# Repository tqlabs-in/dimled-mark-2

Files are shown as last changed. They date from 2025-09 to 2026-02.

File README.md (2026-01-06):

# DimLED Mark II

A simple led dimmer based on ESP-01 Module powered by esphome firmware.

Checkout [iBOM](https://htmlpreview.github.io/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) for more details.

### Renders ( Mark II.b )

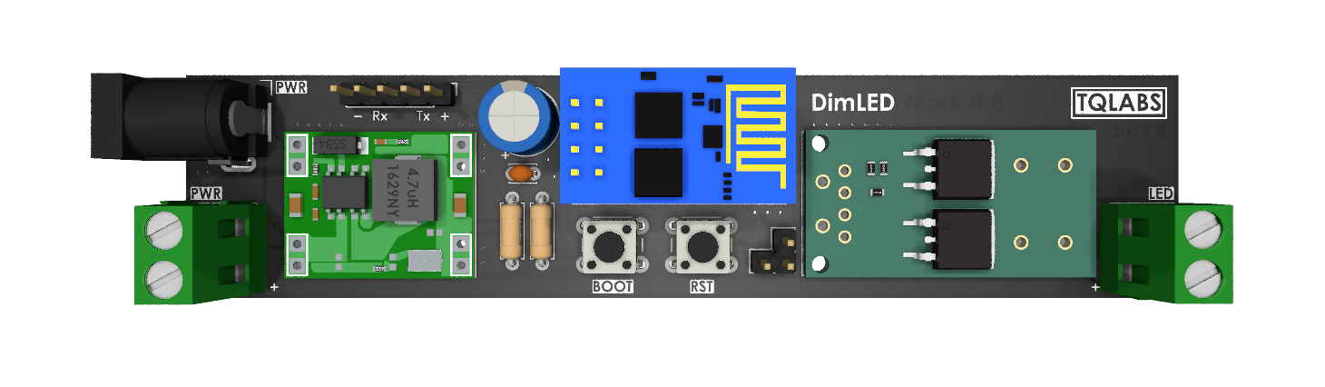
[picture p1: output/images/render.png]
DimLED Mark IIb

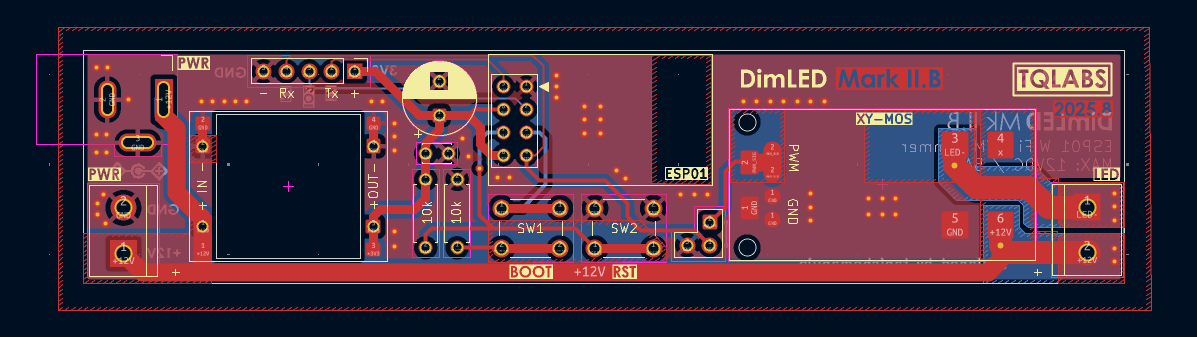
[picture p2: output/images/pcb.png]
PCB


### Operating Power

Max Values:

- Max Voltage: 36VDC
- Max Current: 15A
- Max Power: 400W

> Above specs are contstrained by XY-MOS PWM Trigger Module

Recommended Values:

- less than 10A at 12VDC
- less than 6A at 24VDC

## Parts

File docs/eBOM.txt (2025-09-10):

# Estimate BOM
Date: 13-8-2025

1.	ESP-01 ESP8266			Rs 86	https://robu.in/product/esp-01-esp8266-serial-wifi-wireless-transceiver-module/
2. 	XY-MOS Trigger Module		Rs 25	https://robu.in/product/switch-drive-high-power-mosfet-trigger-module/
3.	Mini MP1584 Buck Module		Rs 34	https://robu.in/product/mini-mp1584-dc-dc-3a-adjustable-buck-module-india/	
4.	2 Pin Screw Block		Rs 10	https://robu.in/product/2-pin-straight-pcb-screw-terminal-block-connector-3-5mm-pitch/
5.	DC-005A Connector		Rs 9	https://robu.in/product/dc-jack-005a/
6.	Tactile Push Button		Rs 2	https://robu.in/product/6x6x5-tactile-push-button-switch/
7.	1000uF THT Radial Capacitor	Rs 8	https://robu.in/product/ers1am102f16ot-aishi-1000uf-10v-%c2%b120-plugind8x16mm-aluminum-electrolytic-capacitors-leaded-rohs/
8.	100nF THT Disk Cap		Rs 1	https://robu.in/product/100nf-50v-through-hole-multilayer-ceramic-capacitor/

X. Component Total			Rs 187	[ 1 x 1,2,3,5,6,7,8 -- 2 x 4 ]
Y. Extras				Rs 9	[ Basic Resistors, ESP01 Headers ]
Z. PCB					Rs 144	[ Robu: 10 for Rs 1440 ]

T. Grand Total				Rs 340

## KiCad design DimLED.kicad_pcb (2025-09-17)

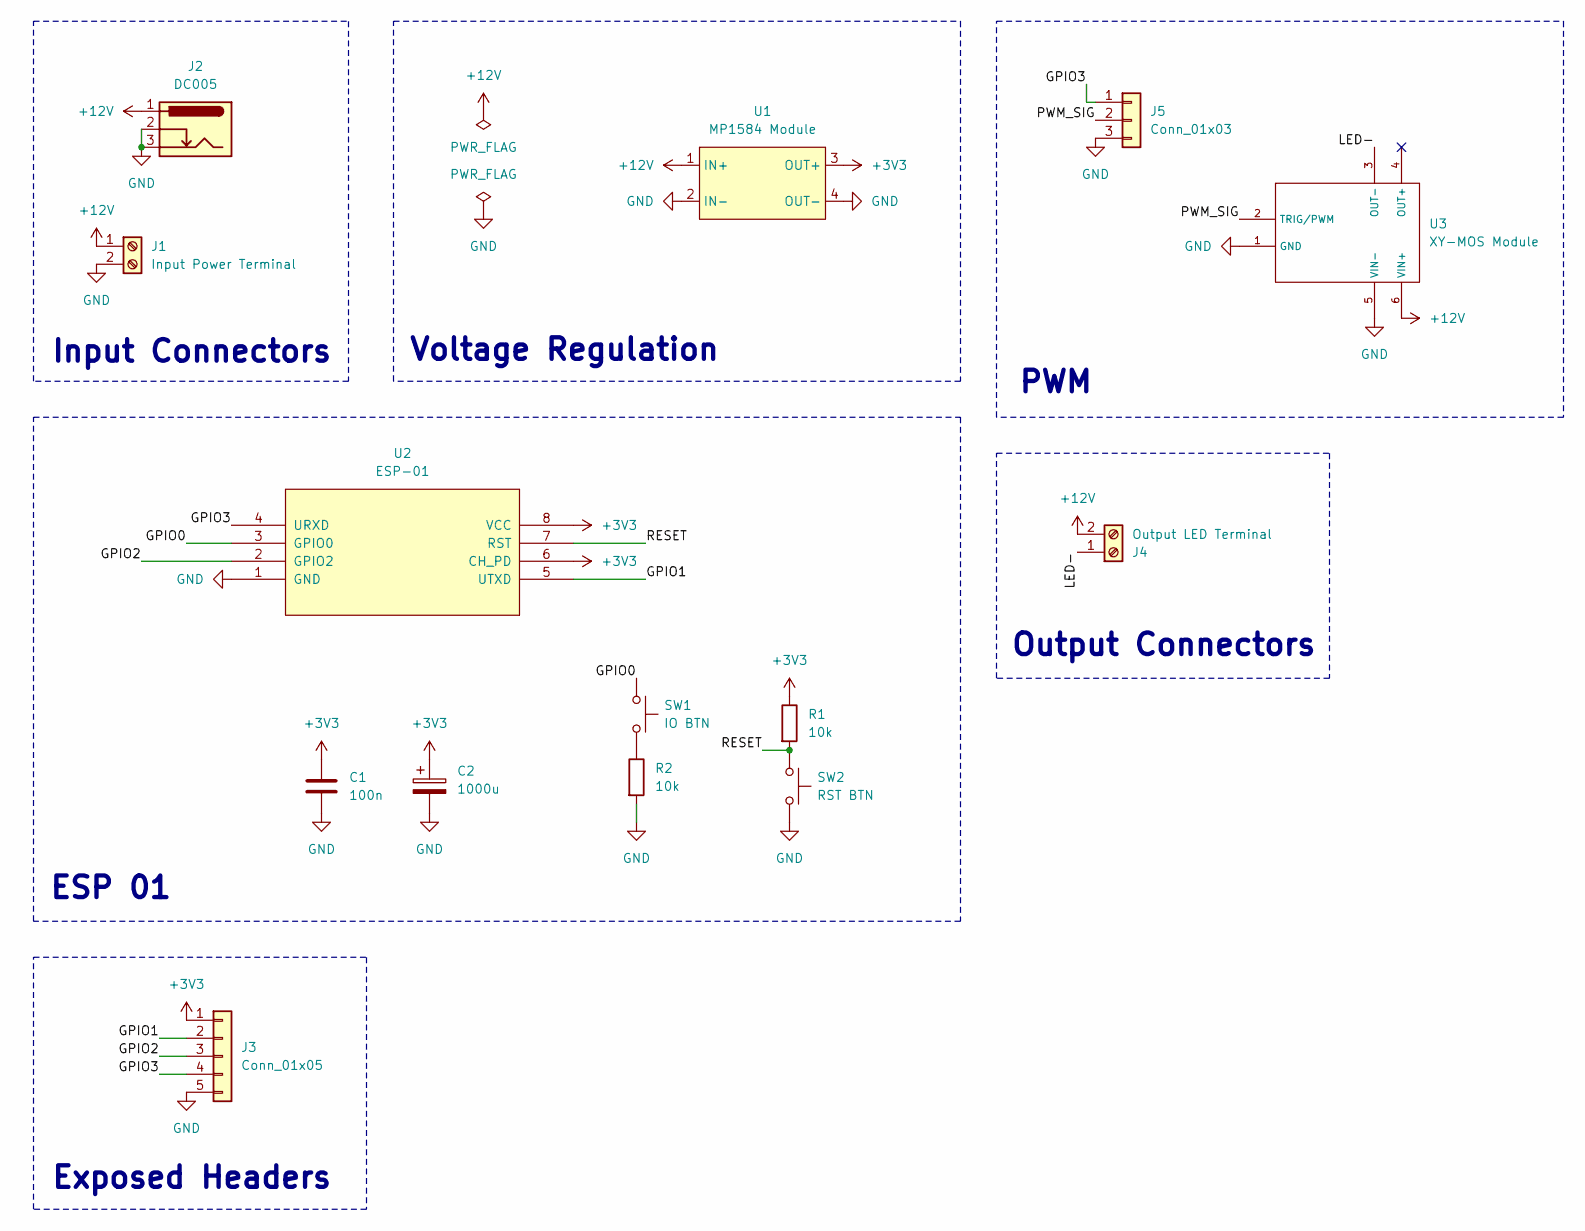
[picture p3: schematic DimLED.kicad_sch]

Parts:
C1: 100n; C_Disc_D3.0mm_W2.0mm_P2.50mm
C2: 1000u; CP_Radial_D8.0mm_P3.80mm
J1: Input Power Terminal; TerminalBlock_bornier-2_P5.08mm
J2: DC005
J3: Conn_01x05; PinHeader_1x05_P2.54mm_Vertical
J4: Output LED Terminal; TerminalBlock_bornier-2_P5.08mm
J5: Conn_01x03; PinHeader_1x03_L_Reverse_P2.54mm_Vertical
R1, R2: 10k; R_Axial_DIN0207_L6.3mm_D2.5mm_P7.62mm_Horizontal
SW1: IO BTN; SW_PUSH_6mm
SW2: RST BTN; SW_PUSH_6mm
U1: MP1584 Module; MP1584-Module_22.1x16.8mm_Cutout_Mixed
U2: ESP-01
U3: XY-MOS Module; XY_MOS-Module_Mounted

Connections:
+3V3: C1.1, C2.1, J3.1, R1.1, U1.3 (OUT+), U2.6 (CH_PD), U2.8 (VCC)
+12V: J1.1, J2.1, J4.2, U1.1 (IN+), U3.6 (VIN+)
/GPIO0: SW1.1, U2.3 (GPIO0)
/GPIO1: J3.2, U2.5 (UTXD)
/GPIO2: J3.3, U2.2 (GPIO2)
/GPIO3: J3.4, J5.1, U2.4 (URXD)
/LED-: J4.1, U3.3 (OUT-)
/PWM_SIG: J5.2, U3.2 (TRIG/PWM)
/RESET: R1.2, SW2.1, U2.7 (RST)
GND: C1.2, C2.2, J1.2, J2.2, J2.3, J3.5, J5.3, R2.2, SW2.2, U1.2 (IN-), U1.4 (OUT-), U2.1 (GND), U3.1 (GND), U3.5 (VIN-)
unnamed: R2.1, SW1.2

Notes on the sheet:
Input Connectors
Voltage Regulation
Output Connectors
ESP 01
PWM
Exposed Headers

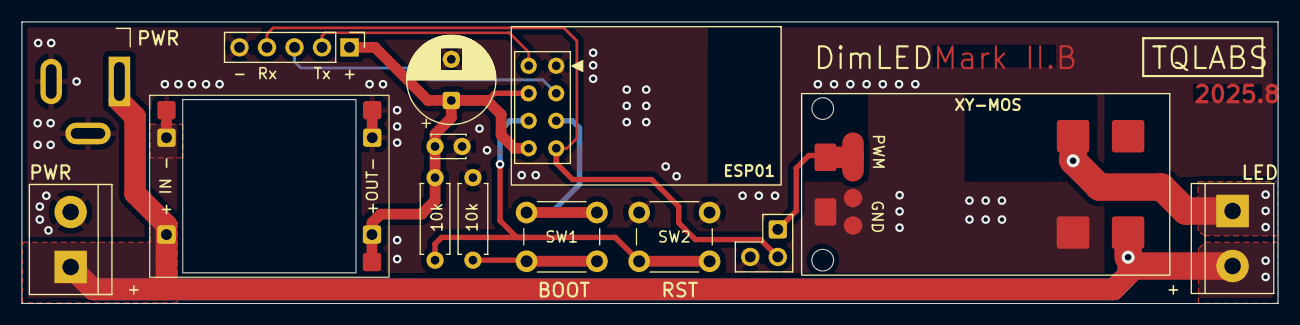
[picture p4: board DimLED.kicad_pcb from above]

Board: 2 copper layers, 116.0 x 26.0 mm, 14 parts (0 on the bottom side), 11 nets.

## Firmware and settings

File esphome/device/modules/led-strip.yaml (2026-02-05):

defaults:
  led_strip_id: led_strip
  led_gpio_number: GPIO3
  led_gpio_inverted: false

globals:
  - id: saved_is_on
    type: bool
    restore_value: yes
    initial_value: "false"

  - id: saved_brightness
    type: float
    restore_value: yes
    initial_value: "0.5"

esphome:
  on_boot:
    - priority: -100
      then:
        - script.execute: restore_state

output:
  - platform: esp8266_pwm
    id: led_strip_output
    pin:
      number: $led_gpio_number
      inverted: $led_gpio_inverted
    frequency: 1000Hz
    zero_means_zero: true

light:
  - platform: monochromatic
    output: led_strip_output
    id: $led_strip_id
    name: LED Strip
    icon: mdi:led-strip-variant
    restore_mode: ALWAYS_OFF
    gamma_correct: 1.8
    default_transition_length: 0.75s
    effects:
      - flicker:
      - pulse:
      - pulse:
          name: "Fast Pulse"
          transition_length: 0.5s
          update_interval: 0.5s
          min_brightness: 0%
          max_brightness: 100%
      - pulse:
          name: "Slow Pulse"
          update_interval: 2s
      - pulse:
          name: "Faded Glow Pulse"
          transition_length:
            on_length: 1s
            off_length: 2s
          update_interval: 4s
          min_brightness: 20%
          max_brightness: 40%

button:
  - platform: template
    name: "Save State"
    icon: mdi:content-save-move
    entity_category: config
    on_press:
      - lambda: |-
          id(saved_is_on) = id($led_strip_id).current_values.is_on();
          id(saved_brightness) = id($led_strip_id).current_values.get_brightness();
      - script.execute: indicate_save
      - script.execute: sync_preferences

  - platform: template
    name: "Restore State"
    icon: mdi:restore
    entity_category: config
    on_press:
      - script.execute: restore_state

script:
  - id: restore_state
    then:
      - light.control:
          id: $led_strip_id
          brightness: !lambda "return id(saved_brightness);"
          state: !lambda "return id(saved_is_on) == true;"

  - id: indicate_save
    mode: restart
    then:
      - if:
          condition:
            light.is_on: $led_strip_id
          then:
            - light.turn_on: $led_strip_id
            - delay: 0.75s
            - light.turn_off: $led_strip_id
            - delay: 0.75s
            - light.turn_on: $led_strip_id
          else:
            - light.turn_off: $led_strip_id
            - delay: 0.75s
            - light.turn_on:
                id: led_strip
                brightness: 0.1
            - delay: 0.75s
            - light.control:
                id: led_strip
                brightness: !lambda "return id(saved_brightness);"
                state: false

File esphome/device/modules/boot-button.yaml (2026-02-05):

---
substitutions:
  light_strip_id: led_strip

globals:
  - id: should_increase
    type: bool
    restore_value: no
    initial_value: "true"

light:
  - id: !extend $light_strip_id
    on_state:
      - lambda: |-
          bool is_on = id(led_strip).current_values.is_on();
          if(!is_on) {
            return;
          }

          float b = id(led_strip).current_values.get_brightness();
          if(b <= 0.05f) {
            id(should_increase) = true;
          } else if(b == 1.0f) {
            id(should_increase) = false;
          }

binary_sensor:
  - platform: gpio
    id: boot_button
    pin:
      number: GPIO0
      mode: INPUT_PULLUP
    filters:
      - invert:
      - delayed_on: 10ms
      - delayed_off: 10ms
    on_multi_click:
      # Hold
      - timing:
          - ON for at least 500ms
        then:
          - lambda: |-
              bool is_on = id(led_strip).current_values.is_on();
              if(!is_on) {
                id(should_increase) = true;
                return;
              }

              float b = id(led_strip).current_values.get_brightness();
              if (b <= 0.05f) {
                id(should_increase) = true;
              } else if (b >= 0.95f) {
                id(should_increase) = false;
              }
          - if:
              condition:
                lambda: "return id(should_increase) == true;"
              then:
                - while:
                    condition:
                      binary_sensor.is_on: boot_button
                    then:
                      - light.dim_relative:
                          id: led_strip
                          relative_brightness: 2%
                          transition_length: 200ms
                      - delay: 100ms
              else:
                - while:
                    condition:
                      binary_sensor.is_on: boot_button
                    then:
                      - light.dim_relative:
                          id: led_strip
                          relative_brightness: -2%
                          transition_length: 200ms
                      - delay: 100ms

      # Double Press
      - timing:
          - ON for at most 400ms
          - OFF for at most 500ms
          - ON for at most 500ms
          - OFF for at least 200ms
        then:
          - light.turn_on:
              id: led_strip
              brightness: !lambda "return id(saved_brightness);"

      # Single Press
      - timing:
          - ON for at most 500ms
          - OFF for at least 200ms
        then:
          - light.toggle: led_strip

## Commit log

2025-09-10 feat: mark II.b
    [DimLED.kicad_pcb, DimLED.kicad_sch]
2025-09-11 feat: gerbers
    [DimLED-B_Cu.gbr, DimLED-B_Mask.gbr, DimLED-B_Silkscreen.gbr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]
2025-09-16 chore: general update
    [DimLED.kicad_pcb, DimLED.kicad_sch]
2025-09-16 fix: bom location
2025-09-17 feat: bottom 12v path
    [DimLED.kicad_pcb]
